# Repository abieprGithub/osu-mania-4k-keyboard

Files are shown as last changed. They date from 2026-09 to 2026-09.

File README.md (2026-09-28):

# 🕹️ Hackpad | osu!mania 4K keyboard

As the name suggest, this is a hackpad that is tuned for osu!mania (the keyboard rhythm game), and only has four keys!
<br><br>

*Note: following image is still just the PCB, will update soon once the CAD is complete.*

Pasted image
<br<br>

For some background, this is technically not my first hackclub project.
I've circled the idea of following the Hackpad mission for some time now, and at the same time, I started playing the game [**osu!mania**](https://www.youtube.com/results?search_query=osu!mania) competitively, while using my laptop's keyboard. After one million taps on a single set of four keys, I finally decided to make one.
Additionally, while my ThinkPad's keyboard is awesome, the actuation force is actually quite heavy (60-70g), which heavily affected my endurance.
<br>

**In summary, this gives the benefit of:**
1) Preventing wear and tear on my keyboard
2) Keeping my hands from breaking apart
3) All the knowledge gained from a stardance hardware project.

<br><br><br>

## ⚙️ Features & Specifications
<br>

(Function diagram TBA)

**Dimensions: 100*42mm**
Made to maximize spacing between the left and right keys

**Peripherals: OLED Display, Rotary Encoder, 4x Standard Cherry MX switches**

**MCU: Seeeed Studio Xiao RP2040**

**Lighting: Per-key SK6812-MINI-E RGB LEDs**

**SMD footprint: 0805 Handsolder**
<br><br><br>

## 🛠️ Build your own

<br>

The assembly process follows a standard hackpad:
1) Order the PCB from JLCPCB (or another fab)
2) Solder all the parts (Although there were smd components, they're all in 0805 handsolder footprints)
3) 3D-print the case
4) Assemble the case, PCB, switches, and OLED display.
5) Upload the firmware.
<br>
All the necessary files are provided in this repository, so go take a look around before doing so.
<br>

### 📜 BOM
1) 1* Seeeed Studio XIAO RP2040
2) 1* EC11 Rotary Encoder (vertical)
3) 1* 128*32 0.91" OLED display
4) 4* Cherry MX-compatible switches
5) 4* SK6812-MINI-E Reverse mount ARGB LEDs
6) 4* 100nF 0805 Capacitors
7) 10* 10K 0805 Resistors
8) 1* 220R 0805 Resistors (optional, bridge R5 if not used)
9) 4* M3 Threaded inserts
10) 4* M3*16 screws
11) 3D printed case
12) 3D printed rotary encoder knob

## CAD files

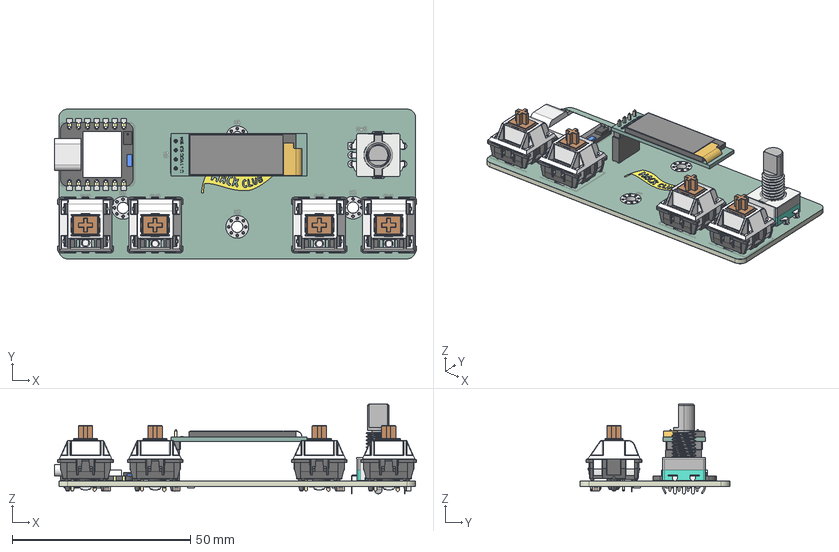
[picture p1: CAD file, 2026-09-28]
CAD/PCB_CAD_model.step
101.4 x 42.0 x 25.1 mm
PinSocket_1x04_P2.54mm_Vertical
128x32-OLED v4
ѽת±ძǷ
SW_Cherry_MX_PCB_cp x 4
SoC_nRF_Sense
Mic_nRF_Sense
Antenna_nRF_Sense
Board
USB
Contact
Pin1 x 4
Pin2 x 4
Pin3 x 4
Pin4 x 4
R_0805_2012Metric x 10
C_0805_2012Metric x 4
osu-mania-4k-unsaved-export-zwdNkn_copper
osu-mania-4k-unsaved-export-zwdNkn_pad
osu-mania-4k-unsaved-export-zwdNkn_via
osu-mania-4k-unsaved-export-zwdNkn_silkscreen x 2
osu-mania-4k-unsaved-export-zwdNkn_soldermask x 2
osu-mania-4k-unsaved-export-zwdNkn_PCB

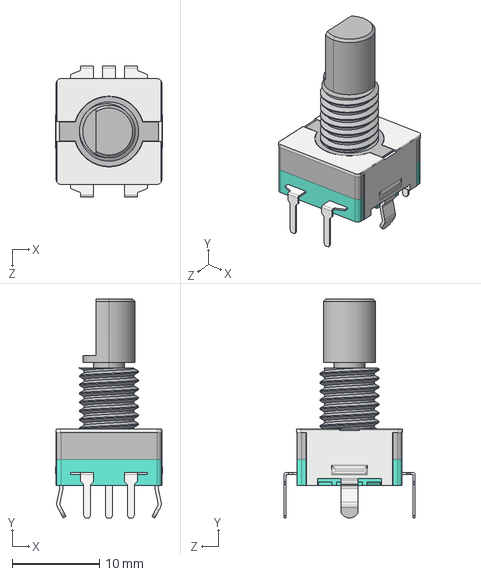
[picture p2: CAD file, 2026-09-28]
PCB/3dmodels/EC11.STEP
12.3 x 25.1 x 15.0 mm

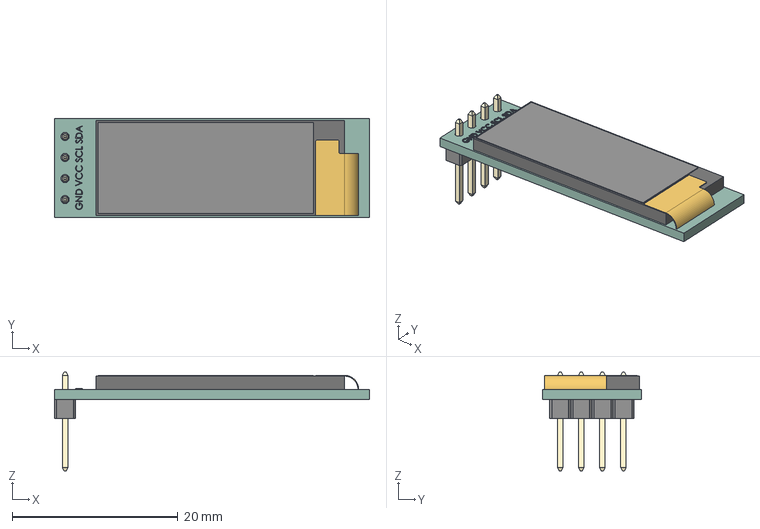
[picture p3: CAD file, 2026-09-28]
PCB/3dmodels/128x32-OLED.STEP
38.0 x 12.0 x 11.9 mm

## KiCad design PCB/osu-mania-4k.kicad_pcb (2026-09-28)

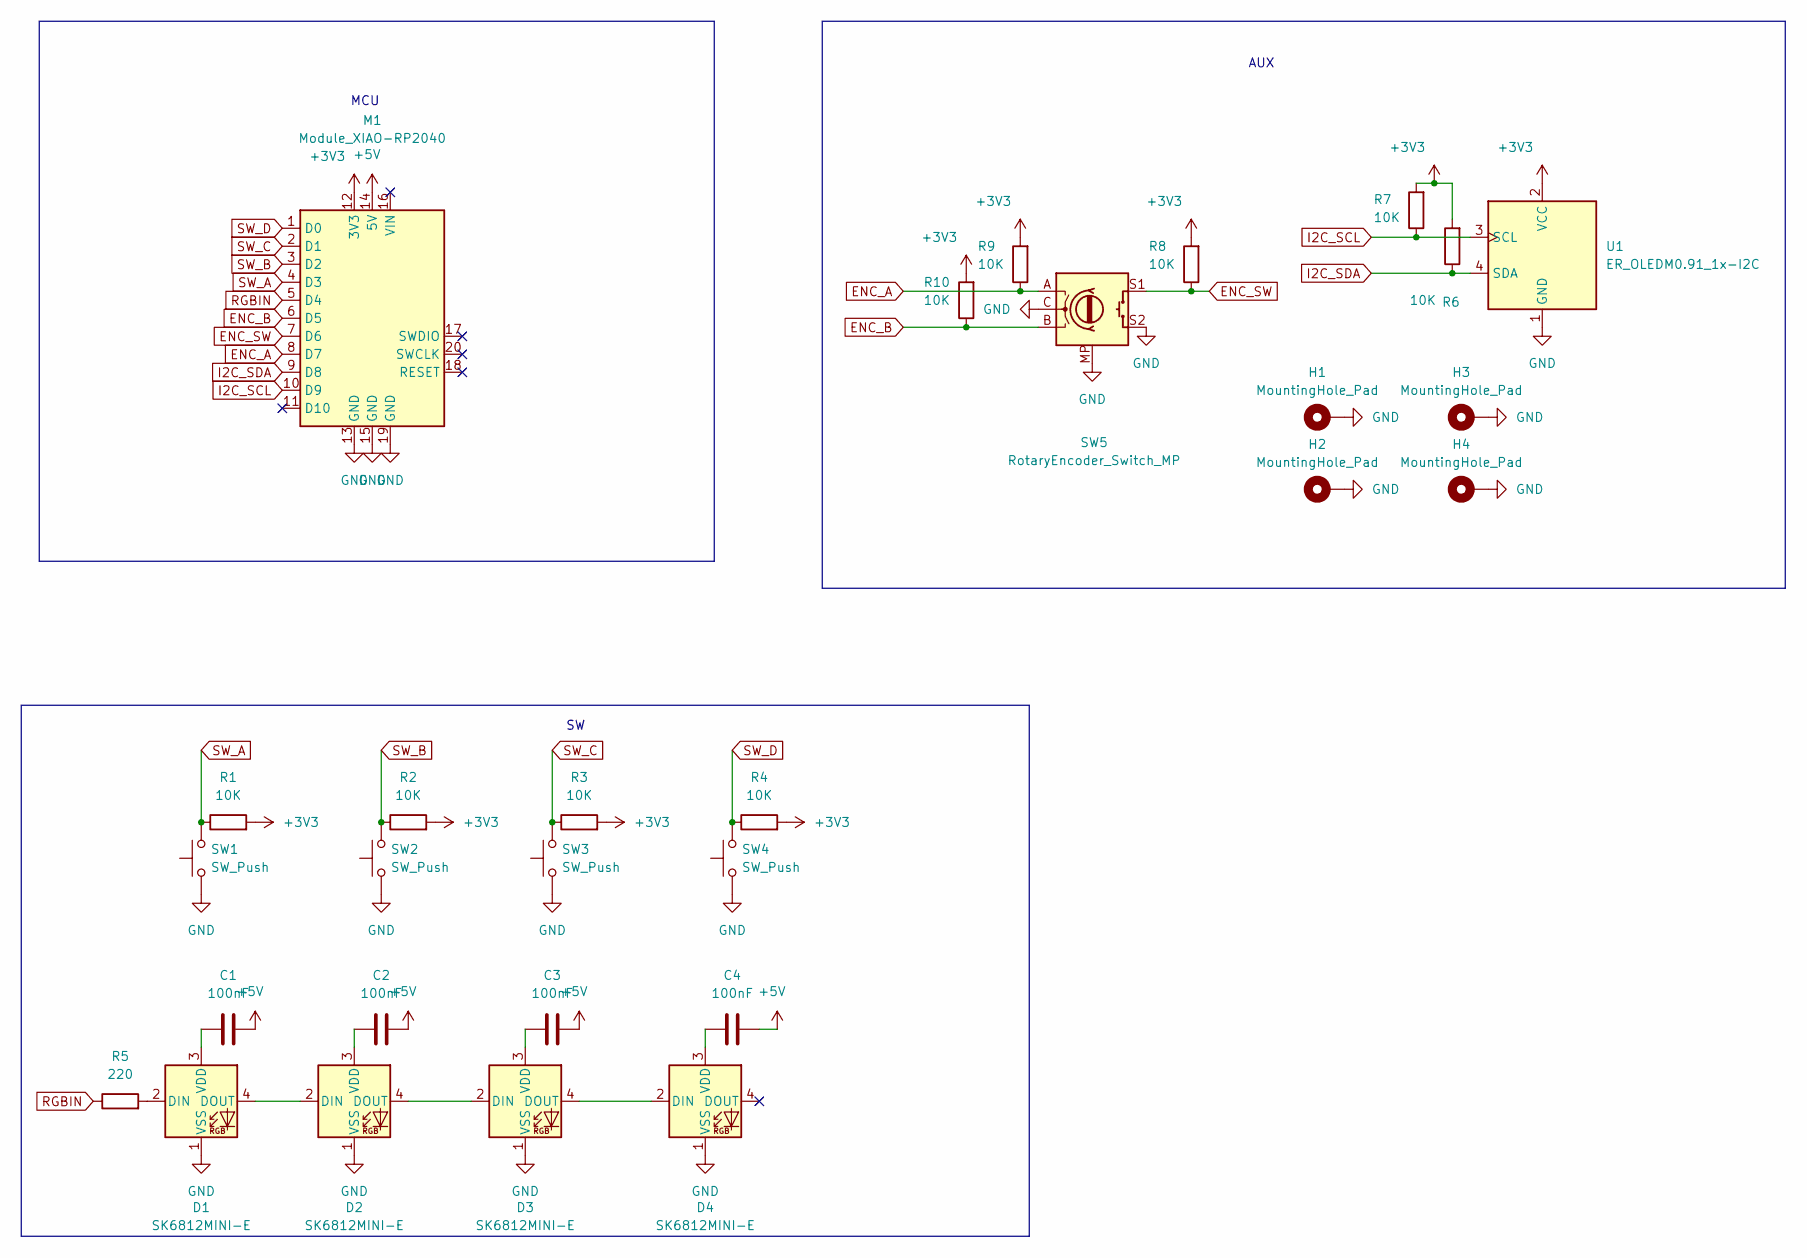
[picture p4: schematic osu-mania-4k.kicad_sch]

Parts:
C1, C2, C3, C4: 100nF; C_0805_2012Metric_Pad1.18x1.45mm_HandSolder
D1, D2, D3, D4: SK6812MINI-E; LED_SK6812MINI-E_3.2x2.8mm_P1.5mm_ReverseMount
H1, H2, H3, H4: MountingHole_Pad; MountingHole_3.2mm_M3_Pad_Via
M1: Module_XIAO-RP2040; SeeedStudio_XIAO_RP2040
R1, R2, R3, R4, R6, R7, R8, R9, R10: 10K; R_0805_2012Metric_Pad1.15x1.40mm_HandSolder
R5: 220; R_0805_2012Metric_Pad1.15x1.40mm_HandSolder
SW1, SW2, SW3, SW4: SW_Push; SW_Cherry_MX_PCB_1.00u
SW5: RotaryEncoder_Switch_MP; RotaryEncoder_Alps_EC11E-Switch_Vertical_H20mm_MountingHoles
U1: ER_OLEDM0.91_1x-I2C

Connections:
+3V3: M1.12 (3V3), R1.2, R2.2, R3.2, R4.2, R6.2, R7.2, R8.2, R9.2, R10.2, U1.2 (VCC)
+5V: C1.2, C2.2, C3.2, C4.2, M1.14 (5V)
ENC_A: M1.8 (D7), R9.1, SW5.A
ENC_B: M1.6 (D5), R10.1, SW5.B
ENC_SW: M1.7 (D6), R8.1, SW5.S1
GND: D1.1 (VSS), D2.1 (VSS), D3.1 (VSS), D4.1 (VSS), H1.1 (1_1), H2.1 (1_1), H3.1 (1_1), H4.1 (1_1), M1.13 (GND), M1.15 (GND), M1.19 (GND), SW1.1, SW2.1, SW3.1, SW4.1, SW5.C, SW5.MP, SW5.S2, U1.1 (GND)
I2C_SCL: M1.10 (D9), R7.1, U1.3 (SCL)
I2C_SDA: M1.9 (D8), R6.1, U1.4 (SDA)
unnamed: D1.2 (DIN), R5.2
unnamed: D1.4 (DOUT), D2.2 (DIN)
unnamed: C1.1, D1.3 (VDD)
unnamed: D2.4 (DOUT), D3.2 (DIN)
unnamed: C2.1, D2.3 (VDD)
unnamed: D3.4 (DOUT), D4.2 (DIN)
unnamed: C3.1, D3.3 (VDD)
unnamed: C4.1, D4.3 (VDD)
RGBIN: M1.5 (D4), R5.1
SW_A: M1.4 (D3), R1.1, SW1.2
SW_B: M1.3 (D2), R2.1, SW2.2
SW_C: M1.2 (D1), R3.1, SW3.2
SW_D: M1.1 (D0), R4.1, SW4.2

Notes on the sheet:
AUX
MCU

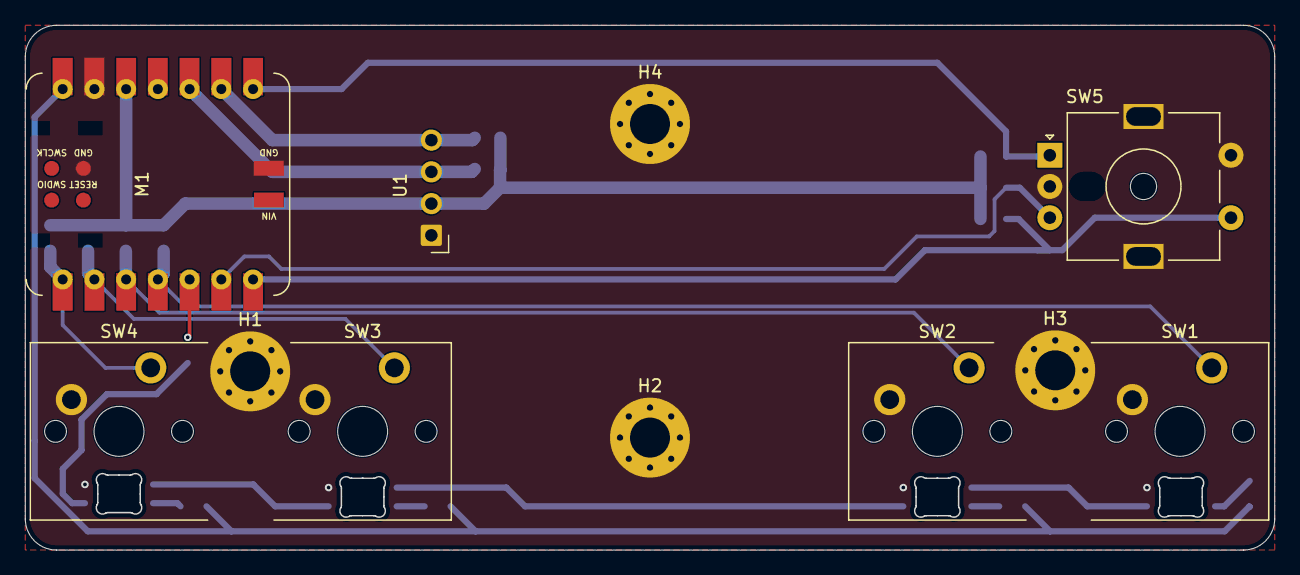
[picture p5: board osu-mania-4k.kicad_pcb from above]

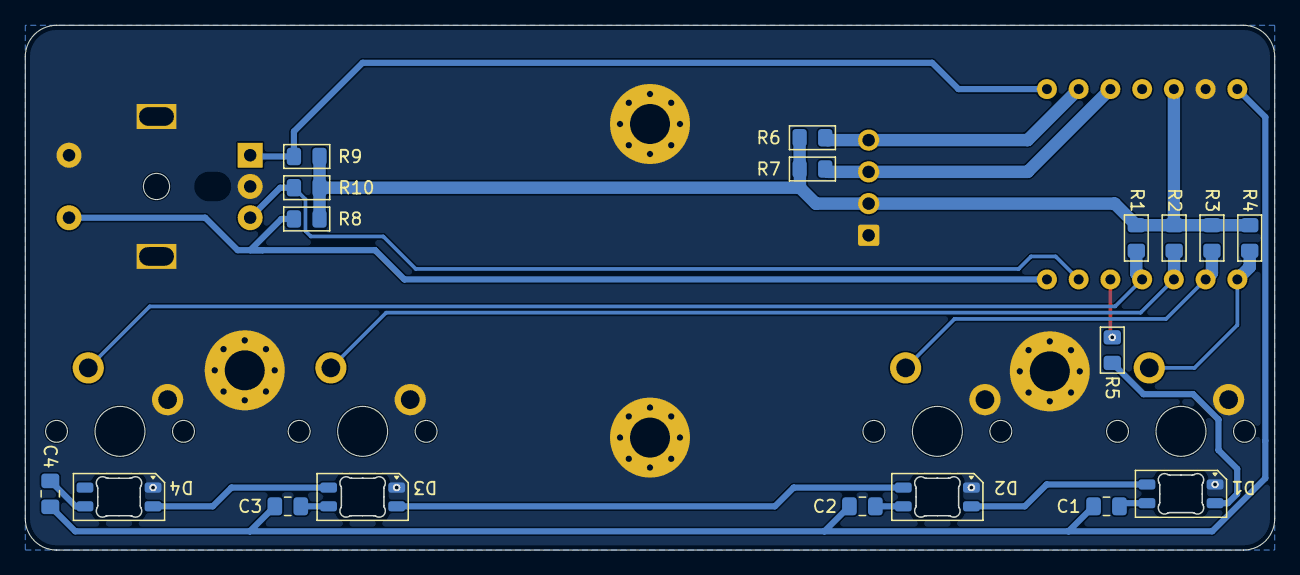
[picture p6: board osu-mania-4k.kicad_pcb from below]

Board: 2 copper layers, 100.0 x 42.0 mm, 29 parts (18 on the bottom side), 21 nets.
